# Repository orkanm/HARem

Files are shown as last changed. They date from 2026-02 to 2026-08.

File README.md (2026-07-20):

# HARem - Home Assistant Remote Controller



**HARem** is a high-performance, minimalist "Thin Client" remote controller designed for the modern smart home. Built on the **ESPHome** ecosystem and powered by the **ESP32-C3**, it provides a boutique-quality physical interface that prioritizes speed, aesthetics, and zero-maintenance operation.

<p align="center">
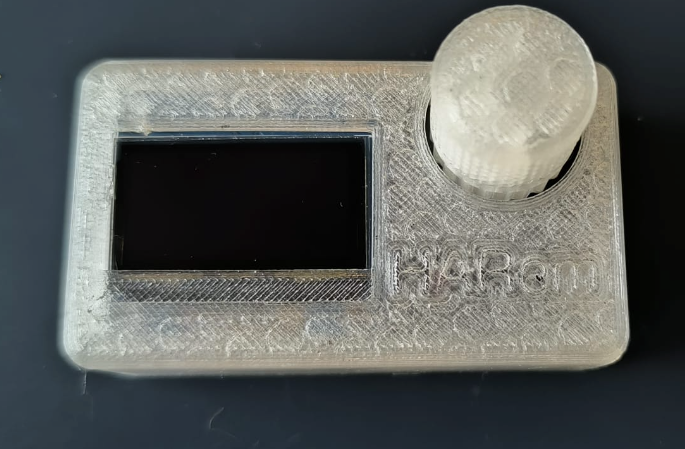
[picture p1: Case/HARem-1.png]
  
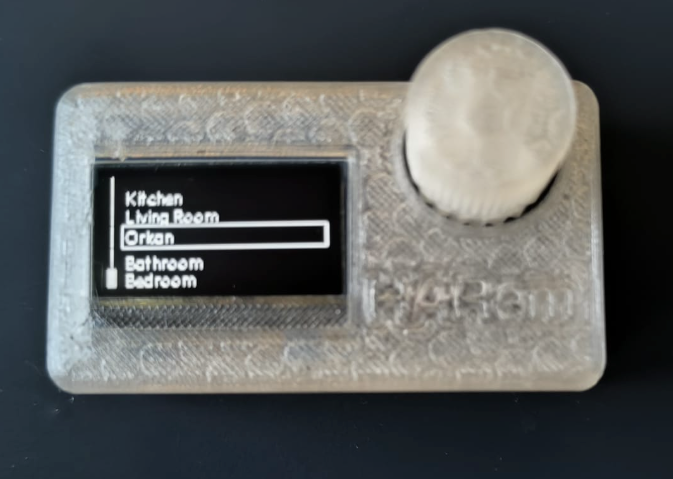
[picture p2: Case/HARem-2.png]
  
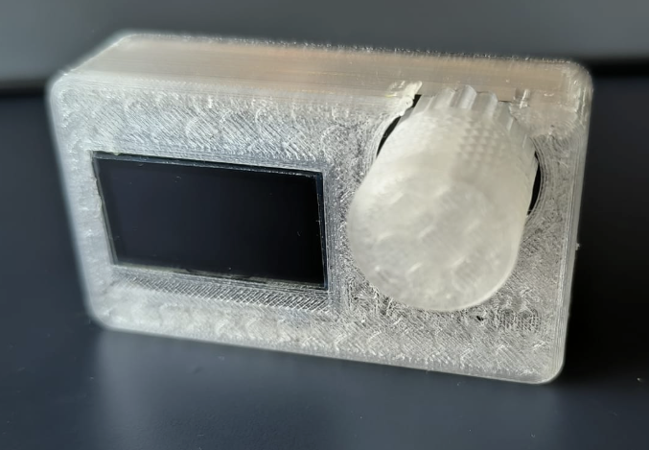
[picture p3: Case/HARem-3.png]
  
</p>

---

## ✨ Features & Architecture

Unlike traditional smart remotes that require manual configuration of every button, HARem operates as a **dynamic viewport** into your Home Assistant instance. Complex logic is handled by Home Assistant Blueprints and Automations, keeping the hardware lightweight and responsive.

- **Zero Maintenance**: Rooms, devices, and states are streamed in real-time. New devices added to a Home Assistant Area automatically appear on the remote.
- **Modern UI**: A 5-line **1.3" OLED** interface featuring Outfit and Montserrat typography, a vertical scrollbar, and hardware-accelerated dynamic marquee for long names.
- **Smart Power**: Deep sleep optimized for sub-1mA idle consumption, utilizing a high-impedance (1MΩ/1MΩ) battery divider and active OLED power management.
- **Guest Mode Protection**: Secure, PIN-protected "Guest Mode" to restrict access to specific areas or devices.
- **Visual Feedback & Control**: Interactive animations, sleep countdowns, and a local on-device menu for contrast and standby settings.

---

## 🚀 Quick Start

1. **Hardware**: ESP32-C3 SuperMini + 1.3" SH1106 OLED + EC11 Rotary Encoder.
2. **Firmware**: 
    * **Option A (Recommended)**: Download the latest **`.factory.bin`** from [Releases](https://github.com/orkanm/HARem/releases) and flash it to **offset 0x0**.
    * **Option B**: Compile locally using `esphome run remote_controller.yaml`.
3. **Home Assistant**: 
    * The device will appear as "HARem" in your dashboard.
    * **IMPORTANT**: If you used the GitHub Release binary, you will be asked for an **Encryption Key**:
        > `7knRB3/EL4Fq8Foul7Yhv+pcABzyLXHSQxa9bTzzQqg=`
    * > [!WARNING]
      > This key is **publicly known**. For security, you should change it in your own configuration and perform an [OTA update](https://esphome.io/components/ota.html) as soon as possible.
    * Follow the [Setup Guide](docs/generic_menu_setup.md) to create the required Helpers and import the logic Blueprint.

---

## 🛠️ Hardware & Assembly

Building your own HARem is straightforward. The project includes custom PCB files and 3D printable case models.

### Interactive Visualizers
Explore the design files directly in your browser:
* **[Interactive PCB 3D Viewer](https://3dviewer.net/index.html#model=https://raw.githubusercontent.com/orkanm/HARem/main/PCB/HARem/HArem.step)** (STEP format)
* **[Interactive Case 3D Viewer](https://3dviewer.net/index.html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,https://raw.githubusercontent.com/orkanm/HARem/main/Case/HARem_Case_2.0-Lid.stl,https://raw.githubusercontent.com/orkanm/HARem/main/Case/Encoder_Knob.stl)** (STL format)
* **[Interactive Schematic](https://kicanvas.org/?github=https://github.com/orkanm/HARem/blob/main/PCB/HARem/HArem.kicad_sch)**
* **[Interactive PCB Layout](https://kicanvas.org/?github=https://github.com/orkanm/HARem/blob/main/PCB/HARem/HArem.kicad_pcb)**

### Design Files
* **[KiCad Project](PCB/HARem/)**: Source files for schematic and board layout.
* **[PCB 3D Model](PCB/HARem/HArem.step)**: Industrial standard 3D file for enclosure design.
* **[3D Printed Case Files](Case/)**: Source FreeCAD project (`.FCStd`), print-ready `.stl` files for the case, lid, and knob, along with a high-resolution `.step` model.

<details>
<summary><b>View Wiring Diagram & Pin Mapping (Click to expand)</b></summary>

```text
       ESP32-C3 Super Mini                 Peripherals
    ┌───────────────────────┐            ┌───────────────┐
    │                       │   Q1(NPN)  │ 1.3" OLED     │
    │          5V / 3.3V ───┼────▶[C]    │               │
    │  GPIO1 (OLED PWR) ────┼────▶[B]    │               │
    │                       │     [E]────┼─▶ [VCC]       │
    │                GND ───┼────────────┼─▶ [GND]       │
    │         GPIO5 (SDA)───┼────────────┼─▶ [SDA]       │
    │         GPIO6 (SCL)───┼────────────┼─▶ [SCL]       │
    │                       │            └───────────────┘
    │                       │            
    │                       │            ┌───────────────┐
    │                       │            │ ROTARY (EC11) │
    │         GPIO8 (CLK) ◀─┼───[100Ω]───┼─ [CLK]        │
    │          GPIO9 (DT) ◀─┼───[100Ω]───┼─ [DT]         │
    │          GPIO4 (SW) ◀─┼───[100Ω]───┼─ [SW]         │
    │                GND  ◀─┼────────────┼─ [GND]        │
    │                       │            └───────────────┘
    │                       │            ┌───────────────┐
    │                       │            │ BAT MONITOR   │
    │                       │            │  [+] BATTERY  │
    │                       │            │   │           │
    │                       │            │  [1MΩ]        │
    │         GPIO0 (ADC) ◀─┼────────────┼───┤           │
    │                       │            │  [1MΩ] [0.1µF]│
    │                       │            │   │      │    │
    │                GND  ◀─┼────────────┼──GND────GND   │
    └───────────────────────┘            └───────────────┘
```

| Component | ESP32-C3 Pin | Type | Notes |
| :--- | :--- | :--- | :--- |
| **OLED VCC** | GPIO1 | Output | Active Power Management (via Q1 NPN) |
| **OLED SDA/SCL** | GPIO5 / GPIO6 | I2C | SSD1306/SH1106 |
| **Encoder CLK/DT** | GPIO8 / GPIO9 | Input | Navigation |
| **Encoder SW** | GPIO4 | Input | Wakeup Trigger |
| **Battery ADC** | GPIO0 | Analog | 1M/1M Divider + 0.1µF Cap |

</details>

---

## 📖 Documentation & Development

* **[Behavior & Interaction Map](docs/behavior_map.md)**: Visual state machines and logic flows for the device interaction.
* **[Project Walkthrough](docs/walkthrough.md)**: Architecture, features, and troubleshooting.
* **[Home Assistant Setup Guide](docs/generic_menu_setup.md)**: How to configure the Home Assistant side.
* **[Environment Installation & Setup Guide](docs/installation.md)**: Guide for setting up your local Python environment and secrets.
* **[Roadmap](TODO.md)**: Planned improvements and future features.

---

## 📛 Trivia: The Name HARem

The name **HARem** is a clever portmanteau of **H**ome **A**ssistant and **Rem**ote, but its inspiration runs deeper into Turkish history and culture. 

In Turkish and Ottoman history, the **Harem** represented the most private, sacred, and protected part of the household. By adopting this name, the project acknowledges the smart home as the modern individual's "inner sanctum." Just as the historical Harem was the heart of the home, this remote serves as the private, primary interface to control and protect the sanctity of your living space.

---

## ☕ Support the Project

If you find this project helpful and would like to support its development, you can buy me a coffee! Your support helps fund new prototypes and keeps the project open-source and free for everyone. 



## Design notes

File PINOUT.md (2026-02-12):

# HARem Hardware Pinout

This document outlines the hardware connections for the HARem Remote Controller (based on ESP32-C3 SuperMini).

## Pin Configuration

| GPIO Pin | Function | Mode | Notes |
| :--- | :--- | :--- | :--- |
| **GPIO 0** | Battery Voltage Monitor | ADC | Through voltage divider (Ultra Low Power: 2x 1MΩ + 0.1µF) |
| **GPIO 1** | OLED Power Supply | OUTPUT | Powers the display. Held LOW in deep sleep. |
| **GPIO 4** | Encoder Button | INPUT_PULLUP | Inverted, Used as Deep Sleep Wakeup Source |
| **GPIO 5** | I2C SDA | I2C Data | Connect to OLED SDA |
| **GPIO 6** | I2C SCL | I2C Clock | Connect to OLED SCL |
| **GPIO 7** | Free | - | - |
| **GPIO 8** | Encoder Pin B | INPUT_PULLUP | Rotary Encoder Clock/Data |
| **GPIO 9** | Encoder Pin A | INPUT_PULLUP | Rotary Encoder Clock/Data |

## Power Connections

- **3.3V**: Main power rail for Peripherals (Encoder, etc.)
- **GND**: Common Ground
- **5V / VBUS**: Charging Input (SuperMini handles charging)

## Power Consumption (Voltage Divider)
With the **Ultra Low Power** design (2x 1MΩ):
- **Resistance**: 2,000,000 Ω (2 MΩ)
- **Max Current (at 4.2V)**: `4.2V / 2MΩ = 2.1 µA`
- **Previous Design (2x 100k)**: `21 µA`
- **Savings**: ~90% reduction in divider leakage.

## Connection Diagram

```mermaid
graph LR
    subgraph ESP32_C3_SuperMini [ESP32-C3 SuperMini]
        GPIO0[GPIO 0<br>ADC0]
        GPIO4[GPIO 4<br>Wakeup]
        GPIO5[GPIO 5<br>SDA]
        GPIO6[GPIO 6<br>SCL]
        GPIO1[GPIO 1<br>Power]
        GPIO8[GPIO 8<br>Enc B]
        GPIO9[GPIO 9<br>Enc A]
        V33[3.3V]
        GND[GND]
    end

    subgraph Peripherals
        subgraph OLED [1.3" OLED Display]
            O_VCC[VCC]
            O_GND[GND]
            O_SDA[SDA]
            O_SCL[SCL]
        end

        subgraph Encoder [Rotary Encoder]
            E_SW[SW]
            E_DT[DT]
            E_CLK[CLK]
            E_COM[COM]
            R1[10k Pullup]
            R2[100 Ohm]
            R3[100 Ohm]
            R4[100 Ohm]
            C1[100nF]
        end

        subgraph Battery_Mon [Battery Monitor]
            BAT[+5VD / BAT]
            R5[1M]
            R6[1M]
            C2[0.1uF]
        end
    end

    %% Wiring
    GPIO1 -->|Power| O_VCC
    GPIO5 --- O_SDA
    GPIO6 --- O_SCL
    GND --- O_GND

    GPIO4 --- R2
    R2 --- E_SW
    E_SW --- R1
    R1 --- V33
    E_SW --- C1
    C1 --- GND

    GPIO8 --- R3
    R3 --- E_CLK
    GPIO9 --- R4
    R4 --- E_DT
    E_COM --- GND
    GND --- E_GND

    BAT --- R5
    R5 --- GPIO0
    GPIO0 --- R6
    R6 --- GND
    
    %% Capacitor for stability
    GPIO0 --- C2
    C2 --- GND
```

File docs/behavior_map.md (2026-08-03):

# HARem Extensive Behavior & Interaction Map

This document exhaustively details the state machines, interaction logic, system flows, and failure handling for the HARem controller, based directly on the ESPHome firmware configuration.

---

## 1. System States, Sleep & Power Flow

```mermaid
stateDiagram-v2
    direction TB
    [*] --> DeepSleep
    
    DeepSleep --> Boot : Button Press (GPIO4 Pulled LOW)
    
    state Boot {
        [*] --> WiFiConnect
        WiFiConnect --> APIConnect : Connects to Home Assistant
        APIConnect --> StaleStateClear : Send 'refresh' to HA (First wake only)
        StaleStateClear --> NormalOperation
    }
    
    Boot --> NormalOperation
    
    state NormalOperation {
        [*] --> IdleTimerRunning
        IdleTimerRunning --> SleepCountdown : Wait (Standby Duration)
        SleepCountdown --> DeepSleepPrep : Wait 5s
        SleepCountdown --> IdleTimerRunning : Any Input
    }
    
    DeepSleepPrep --> DeepSleep : Disconnect & Power Down OLED
```

### Deep Sleep & OLED Power Management
1. **Sleep Entry**: 
   - UI displays "SLEEPING" and a 5-second countdown timer.
   - Screen goes black in software.
   - `GPIO1` is pulled `LOW` and permanently locked using `gpio_hold_en()`. This guarantees the `Q1` NPN transistor cuts power to the OLED `VCC` rail entirely.
   - ESP32-C3 enters deep sleep for 1 day.
2. **Wake Up**:
   - Pushing the rotary encoder wakes the ESP32 via GPIO4.
   - Boot runs: `GPIO1` lock is released (`gpio_hold_dis()`), power is restored to the OLED, and a 100ms delay ensures OLED boot stability.
   - All internal UI states (`settings_mode`, `control_mode`, `guest_pin_mode`, etc.) are reset to `false` to prevent the UI from getting stuck if it went to sleep mid-interaction.

### The "Stale State Clear"
Because the remote connects to Home Assistant asynchronously after waking up, the controller checks `esp_sleep_get_wakeup_cause()`. If it woke from deep sleep, it sets `boot_clear_done = true` and sends a `refresh` event to Home Assistant to wipe out any leftover `line_5` or overlay dimming states from the previous session before rendering the UI.

---

## 2. Encoder Input & Normal Interaction Flow

```mermaid
flowchart TD
    Press[Button Pressed] --> HoldCheck{Hold Duration?}
    HoldCheck -->|"< 10ms"| Debounce(Ignore: Debounce)
    HoldCheck -->|"10ms - 800ms"| ShortClick(Short Click)
    HoldCheck -->|"800ms - 3.5s"| LongClick(Long Click)
    HoldCheck -->|"> 4s"| SettingsHold(Auto-Enter Settings)
    
    ShortClick --> ModeCheck{Current Mode?}
    ModeCheck -->|Control Mode| ExitControl[Exit Control Mode]
    ModeCheck -->|Settings Mode| SettingsAction[Execute Settings Action]
    ModeCheck -->|Normal Mode| ClickHA[Send 'click' to HA]
    
    LongClick --> LModeCheck{Current Mode?}
    LModeCheck -->|Settings Mode| CancelSettings[Exit Settings/Cancel PIN]
    LModeCheck -->|Normal Mode| BackHA[Send 'back' to HA]
```

### The "Sloppy Click" Filter
When pushing the encoder in **Control Mode**, it's common for a user's finger to accidentally rotate the knob a tiny bit during the press/release. 
- If `processed_rotate_hold` is flagged (meaning a rotation occurred while the button was down), the release event is consumed and *ignored* instead of triggering an exit click. This ensures smooth dimming without accidentally exiting.

### Normal Navigation
- **Rotate Clockwise (Free)**: Sends `esphome.remote_action` -> `next`
- **Rotate Counter-Clockwise (Free)**: Sends `esphome.remote_action` -> `prev`

---

## 3. Control Mode & Bulk Power Control Flow

Control Mode allows continuous parameter adjustment (like brightness or volume) or triggering Bulk Room Power Control without sending repetitive clicks.

```mermaid
stateDiagram-v2
    [*] --> Normal
    Normal --> PressAndTwist : Press + Rotate
    
    state PressAndTwist {
        direction LR
        [*] --> CheckLocation
        CheckLocation --> RoomList : ROOT Menu (Room List) ?
        RoomList --> SendBulkEvent : YES (Sends 'rotate_cw_hold' / 'rotate_ccw_hold')
        CheckLocation --> EntityList : In Room (Entity List) ?
        EntityList --> IsDimmable : Status has '*' ?
        IsDimmable --> SendDimEvent : YES (Control Mode & Dim Overlay)
        IsDimmable --> Reject : NO (Overlay 'Not Supported')
    }
    
    SendBulkEvent --> PromptActive : HA sets Overlay ('Turn ON Room?')
    PromptActive --> ExecuteBulk : Short Click on Prompt (Sends 'click' -> HA turns ON/OFF room)
    SendDimEvent --> SendDimEvent : Rotate (Adjusts Brightness/Vol)
    SendDimEvent --> Normal : Short Click (Exits Control Mode)
```

**Interaction Rules**:
1. **Bulk Room Power**: Executing Press & Twist on the `ROOT` menu sends `rotate_cw_hold` or `rotate_ccw_hold` to Home Assistant, prompting `Turn ON Room?` or `Turn OFF Room?`.
2. **Prompt Click Confirmation**: Short-clicking while a confirmation prompt (ending with `?`) is displayed fires `action: click`, triggering Home Assistant to execute the bulk power service across all included entities.
3. **Hotspot & OTA Guarding**: While the `WIFI FAILED!` hotspot overlay or `UPDATING...` OTA screen is active, all encoder rotations and button events are blocked locally to prevent background state drift.

---

## 4. Settings Menu State Machine

The settings menu is 100% locally rendered, decoupling critical device config from the Home Assistant server.

```mermaid
flowchart LR
    Enter[Hold >4s] --> Nav[Scroll Settings 0-10]
    Nav -->|Rotate| Nav
    Nav -->|Short Click| Eval[Evaluate Selection]
    
    Eval -->|Index < 4 or Index == 9| Edit[Toggle Edit Mode]
    Edit -->|Rotate| AdjustVar[Change Variable / Demo Mode]
    AdjustVar -->|Short Click| EditExit[Save & Exit Edit Mode]
    EditExit --> Nav
    
    Eval -->|Index 4, 5, 6, 7| Action[Toggle Guest / LeftHand / ChangePIN / WiFi Rescan]
    Eval -->|Index 10| Exit[Exit Settings]
```
    
    Eval -->|Index = 4 (Guest)| ToggleGuest[Toggle Guest]
    ToggleGuest -->|If ON| PINFlow
    ToggleGuest -->|If OFF| SendToggle[Send 'toggle_guest']
    
    Eval -->|Index = 6| PINFlow[Enter PIN Flow]
    Eval -->|Index = 7| Rescan[Rescan WiFi]
    Eval -->|Index = 9| Exit[Exit Settings]
```

### Editable Variables
1. **Brightness**: `10%` to `100%` (step 10) - Updates display contrast instantly.
2. **Standby Timer**: `10s` to `300s` (step 10) - `standby_duration_v2`
3. **Sleep Timer**: `10s` to `300s` (step 10) - `sleep_timeout_v2`
4. **Animations**: Toggle `enable_animations_v2` (1 or 0).
5. **Left Hand Mode**: Inverts display rendering 180° for left-handed use.

---

## 5. Security: PIN Validation & Change Flow

To prevent unauthorized users from leaving "Guest Mode", PIN validation is strictly enforced locally. 

```mermaid
flowchart TD
    Start[User selects Change PIN] --> Stage1[Verify Old PIN]
    
    Stage1 --> Input[Rotate 00-99, Click]
    Input --> Check1{Matches Old PIN?}
    
    Check1 -->|No| Error[Show 'WRONG!']
    Error --> Input
    
    Check1 -->|Yes| Stage2[Set New PIN]
    Stage2 --> Input2[Rotate 00-99, Click]
    Input2 --> Stage3[Confirm New PIN]
    
    Stage3 --> Input3[Rotate 00-99, Click]
    Input3 --> Check2{Matches Temp PIN?}
    
    Check2 -->|No| Error2[Show 'NO MATCH']
    Error2 --> Stage2
    
    Check2 -->|Yes| Success[Show 'PIN SAVED']
    Success --> SaveToMemory[Write Flash]
    SaveToMemory --> Exit[Exit PIN Flow]
```

---

## 6. Battery & OTA Behavior

### Battery Voltage Monitoring (ADC)
* Uses a high impedance `1MΩ / 1MΩ` voltage divider connected to `GPIO0`.
* The ADC reads raw voltage, multiplies by `2.0`, and converts to a strict `0-100%` scale assuming a LiPo range of `3.0V` to `4.1V`.
* **Low Battery UI Intercept**:
  * If `< 90%` upon boot, a 3-second warning is displayed.
  * If `< 20%` while awake, the screen flashes a high-priority, full-screen "LOW BATTERY!" warning immediately overlaying whatever was on screen.

### OTA Update Handling
* Over-The-Air updates trigger a high-priority override.
* `on_begin`: Idle timer is completely stopped, locking the screen `ON`.
* `on_progress`: Renders a custom full-screen progress bar (`ota_progress`).
* `on_end`: Shows "REBOOTING..." and reboots cleanly.

### Network Fallback
* If Wi-Fi drops, the ESP32 waits 3 minutes (`180s`). If connection isn't restored, it reboots.
* If it cannot connect to any configured Wi-Fi network, it falls back to AP (Captive Portal) Mode. The UI immediately detects this and draws a full-screen alert showing the Hotspot Name, Password, and IP for emergency provisioning.

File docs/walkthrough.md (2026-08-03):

# ESPHome Generic Remote Controller - Project Walkthrough

A universal, maintenance-free remote controller for Home Assistant, powered by ESPHome. It automatically discovers your Rooms and Devices, rendering them on a crisp OLED display.

## System Architecture

The remote operates as a "Thin Client". It handles physical I/O and displaying text, while Home Assistant handles all logic, state management, and menu rendering.

```mermaid
sequenceDiagram
    participant U as User
    participant R as ESPHome Remote
    participant HA as Home Assistant
    
    U->>R: Rotates Knob (Next)
    R->>HA: Fires event 'esphome.remote_action' (action: next)
    
    rect rgb(30, 30, 45)
        note right of HA: Automation Triggered
        HA->>HA: Calculate new Index
        HA->>HA: Fetch Areas/Devices List
        HA->>HA: Determine text for 5 Lines
    end
    
    HA-->>R: Updates 'input_text.harem_line_1'
    HA-->>R: Updates 'input_text.harem_line_2'
    HA-->>R: Updates 'input_text.harem_line_3' (Selected)
    HA-->>R: Updates 'input_text.harem_line_4'
    HA-->>R: Updates 'input_text.harem_line_5'
    
    R->>U: Display Refreshes
```

## Features

### 1. Zero-Maintenance Menu
*   **Dynamic**: No hardcoding device names on the chip.
*   **Auto-Sync**: Add a light to a room in HA -> It appears on the remote instantly.
*   **Hierarchical**: `Areas List` -> `Entities List` -> `Toggle Entity`.

### 2. High-Density Display
*   **5 Lines of Context**:
    *   **Lines 1, 2, 4, 5**: Contextual items (Small Font 10px).
    *   **Line 3**: Selected Item (Header Font 12px, highlighted with a **full-width outline box**).
*   **Vertical Scrollbar**: Positioned on the **left side** for better accessibility and aesthetics.
*   **Marquee Effect**: Long text on the selected line auto-scrolls with a hardware-accelerated UI mask to prevent spillover.

### 3. Navigation Controls
*   **Rotate**: Scroll Up/Down.
*   **Click**: Enter Room / Toggle Device. (Short Click: 10ms - 300ms)
*   **Long Press (301ms+)**: Back to previous menu. (No dead zone)

### 4. Smart Power Management
*   **Standby Mode**: Display turns off after 60s of inactivity to prevent burn-in.
*   **Wake-on-Click**: First click only wakes the device (no accidental actions).

### 5. Action Feedback
*   **Instant Feedback**: "Turning On..." / "Turning Off..." overlay appears immediately on click.
*   **Timeout Logic**: If device state doesn't change in 10s, displays "Failed!".
*   **Auto-Dismiss**: Overlay vanishes instantly when the new state is confirmed by Home Assistant.

### 6. Local Settings Menu
*   **Access**: Long press knob (>1.5s).
*   **Controls**: Rotate to Navigate, Click to Edit/Save.
*   **Features**:
    *   **Brightness**: Adjust OLED contrast (0-100%).
    *   **Standby**: Adjust timeout (10-300s).
    *   **Sleep**: Adjust sleep timeout (10-300s).
    *   **Animations**: Toggle smooth UI progress bar animations (ON/OFF).
    *   **Demo Mode**: Standalone offline demonstration mode (`Demo: [ON]` / `Demo: [OFF]`).
    *   **Network Info**: View SSID and IP Address.
*   **Storage**: Settings persist in flash memory (retained after reboot).

### 7. Emergency Hotspot (Changing WiFi)
If the remote cannot connect to any configured WiFi network (e.g., you changed your router password or moved to a new house):
1.  **Wait**: After powering on, wait 60 seconds.
2.  **Connect**: Look for WiFi named **"Harem Fallback Hotspot"** on your phone/laptop.
3.  **Password**: Enter `4jNJPSLAfajjdHh3`.
4.  **Configure**: A portal should pop up automatically (or go to `192.168.4.1`).
5.  **Select**: Click your new WiFi network and enter the password. The device will save it and reboot.

> [!NOTE]
> **Input Guarding**: While the "WIFI FAILED!" hotspot screen or OTA update screen is displayed, rotary encoder rotation and button press/release actions are completely suppressed to prevent background state modifications.

### 8. Final Verification (v0.7.0)
- **Startup**: Verified sequence (Splash -> Waiting -> v0.7.0).
- **Navigation**: "Back" button reliably returns to previous room.
- **Refresh Sync**: Explicit `refresh` event ensures the menu reappears instantly after exiting Dimming/Volume overlays.
- **Display**: Selection highlight moved to `x=8` to ensure pixel-perfect corners and zero interference with the scrollbar.
- **Versioning**: Centralized version management via `substitutions` block.

### 9. Final Verification (v0.7.1)
- **Linear Scrolling**: Verified that short menus correctly clamp at boundaries, avoiding duplicate wrapped items.
- **Dimming Status Evaluation**: Verified that dimming capabilities are correctly detected when the entity does not have a `friendly_name` attribute set.

### 10. Final Verification (v0.7.2)
- **Overlay Dismissal & Timeout**: Verified 5-second inactivity timeout and long-press BACK button overlay dismissal across bulk room power and individual device dimming modes.
- **Line 5 Sync**: Verified synchronized 5-line rendering upon returning from overlays.
- **Hotspot Overlay Input Protection (Issue #42)**: Verified that user inputs are ignored while hotspot or OTA overlays are active, and transient settings states reset cleanly upon entering hotspot mode.
- **Bulk Room Power Control**: Verified Press & Twist on room items on the ROOT menu forwards events to Home Assistant, and confirmed button clicks send `action: click` to execute bulk room turn on (`Turn ON Room?`) / turn off (`Turn OFF Room?`).

## 5. Next Steps
- [ ] Mount hardware in final enclosure.
- [ ] 3D Print case (files are available in the Case/ directory).
- [ ] Enjoy!

## Setup Guide

### 1. Home Assistant Helpers (Pick 1 of 2 Methods)

#### ✅ Option A: Drop-in Package (Professional)
The fastest method. Creates all 11 required helpers.
1. Copy [harem_package.yaml](../home_assistant/harem_package.yaml) to your Home Assistant `/config/packages/` folder.
2. In `configuration.yaml`, ensure you have: `homeassistant: { packages: !include_dir_named packages }`.
3. Restart Home Assistant. **Done.**

#### 🛠 Option B: Manual Configuration
Create these 11 Helpers manually in **Settings > Helpers**:

| Helper Entity ID | Type | Purpose |
| :--- | :--- | :--- |
| `input_text.harem_menu_path` | Text | Tracks current location (`ROOT` or Area Name). |
| `input_number.harem_menu_index` | Number | Tracks scroll position (0-1000). |
| `input_number.harem_menu_total` | Number | Tracks total number of items in the list. |
| `input_text.harem_line_1` | Text | Display Line 1 content. |
| `input_text.harem_line_2` | Text | Display Line 2 content. |
| `input_text.harem_line_3` | Text | Display Line 3 content (Selected). |
| `input_text.harem_line_3_status` | Text | Display Line 3 state (e.g. `(on) *`). |
| `input_text.harem_line_4` | Text | Display Line 4 content. |
| `input_text.harem_line_5` | Text | Display Line 5 content. |
| `input_text.harem_overlay` | Text | Feedback Screen Message (Pop-up). |
| `input_boolean.harem_guest_mode`| Toggle | Controls the security status. |

### 2. Home Assistant Automation (Blueprint)
All logic is handled securely via Blueprint.
1.  Copy the content of [harem_remote.yaml](../blueprints/harem_remote.yaml) into your Home Assistant `/config/blueprints/automation/` folder.
2.  Go to **Settings > Automations & Scenes > Blueprints**.
3.  Click **Create Automation** next to "HARem: Universal ESPHome Remote Controller".
4.  Select your helpers from the dropdowns and click **Save**.

**[View Setup Details](generic_menu_setup.md)**

### 3. ESPHome Firmware
The firmware handles hardware debouncing, display rendering, and event transmission.
**[View Firmware Config](../remote_controller.yaml)**

## Troubleshooting

### "Line 5 is missing"
*   **Cause**: You forgot to create `input_text.harem_line_5` in Home Assistant.
*   **Fix**: Create the text helper with that exact Entity ID.

### "Display is blank"
*   **Cause**: Automation hasn't run yet or inputs are empty.
*   **Fix**: Rotate the knob once to force an update.

### "Long press triggers click"
*   **Cause**: You released the button too fast (in the dead zone between 350ms-600ms).
*   **Fix**: Hold the button clearly for >0.6s until you see the action happen.

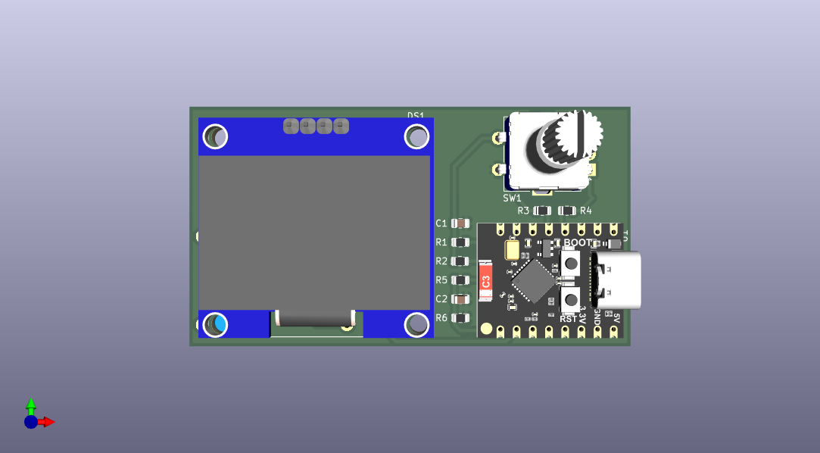
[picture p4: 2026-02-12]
PCB/HARem/HArem_PCB.png

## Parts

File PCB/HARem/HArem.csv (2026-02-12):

Id | Designator | Footprint | Quantity | Designation | Supplier and ref
1 | C2 | C_0805_2012Metric | 1 | 0.1uF
2 | R3,R4,R2 | R_0805_2012Metric | 3 | 100
3 | R6,R5 | R_0805_2012Metric | 2 | 1M
4 | C1 | C_0805_2012Metric | 1 | 100nF
5 | U1 | MODULE_ESP32-C3_SUPERMINI_TH | 1 | ESP32-C3_SUPERMINI_TH
6 | SW1 | RotaryEncoder_Alps_EC11E-Switch_Vertical_H20mm_MountingHoles | 1 | RotaryEncoder_Switch
7 | DS1 | LCD_OLED_128X64_1.3_I2C | 1 | OLED_128X64_1.3_I2C
8 | Q1 | SOT-23 | 1 | BC817
9 | R1 | R_0805_2012Metric | 1 | 10K
10 | U2 | TP4056-Module | 1 | ~
11 | J1 | JST_S2B-PH-K-S_LF__SN_ | 1 | S2B-PH-K-S_LF__SN_

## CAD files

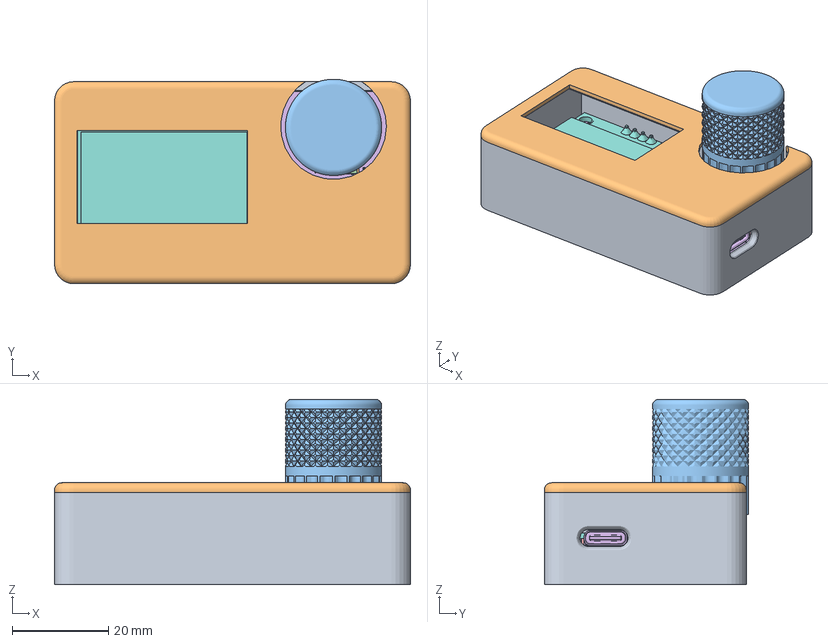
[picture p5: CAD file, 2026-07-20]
Case/HARem_Case_2.0.FCStd
74.0 x 42.5 x 38.5 mm
C_0805_2012Metric
R_0805_2012Metric
R_0805_2012Metric001
R_0805_2012Metric002
C_0805_2012Metric001
usb4215-03-a_1
RES0201 v1
C0201 v4
C0201 v001
C0402 v1
C0402 v001
C0201 v002
RES0201 v001
Cathode
Anode
Cathode Bar
QFN-32 V6 v2
C0201 v003
C0201 v004
C0201 v005
RES0201 v002
RES0201 v003
RES0201 v004
RES0201 v005
RES0201 v006
RES0201 v007
RES0201 v008
C0402 v002
switch 3x4x2mm - 2 Pad v2
switch 3x4x2mm - 2 Pad v001
C0201 v006
C0201 v007
C0201 v008
RES0201 v009
RES0201 v010
C0402 v003
C0201 v009
EC11 Rotary Encoder Dode Switch-15mm
R_0805_2012Metric003
Display 1.3 OLED (Mauro) v5
SOT-23
R_0805_2012Metric004
R_0805_2012Metric005
board
USB_Type_C_Connector
8205A_2045
DW01-P
small1005_smd_resistor
small1005_smd_resistor (1)
small1005_smd_capacitor
smd_capacitor
SOP-8_4056E
small1005_smd_resistor001
solder_dot_round
solder_dot_round (1)
solder_dot_round (2)
solder_dot_round (3)
small1005_smd_capacitor (1)
LED2
LED2 (1)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

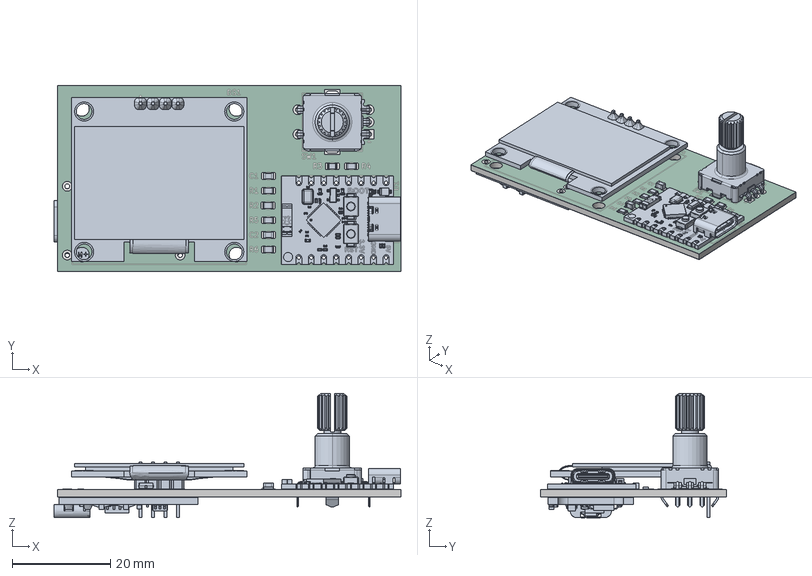
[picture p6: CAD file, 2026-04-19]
PCB/HARem/HArem.step
70.7 x 38.0 x 25.3 mm
C_0805_2012Metric x 2
R_0805_2012Metric x 6
usb4215-03-a_1
RES0201 v1 x 11
C0201 v4 x 10
C0402 v1 x 4
Cathode
Anode
Cathode Bar
QFN-32 V6 v2
switch 3x4x2mm - 2 Pad v2 x 2
EC11 Rotary Encoder Dode Switch-15mm
Display 1.3 OLED (Mauro) v5
SOT-23
board
USB_Type_C_Connector
8205A_2045
DW01-P
small1005_smd_resistor x 2
small1005_smd_resistor (1)
small1005_smd_capacitor
smd_capacitor
SOP-8_4056E
solder_dot_round
solder_dot_round (1)
solder_dot_round (2)
solder_dot_round (3)
small1005_smd_capacitor (1)
LED2
LED2 (1)
small1005_smd_resistor (2)
small1005_smd_resistor (4) x 2
soldering
HArem_copper
HArem_pad
HArem_via
HArem_silkscreen x 2
HArem_soldermask x 2
HArem_PCB

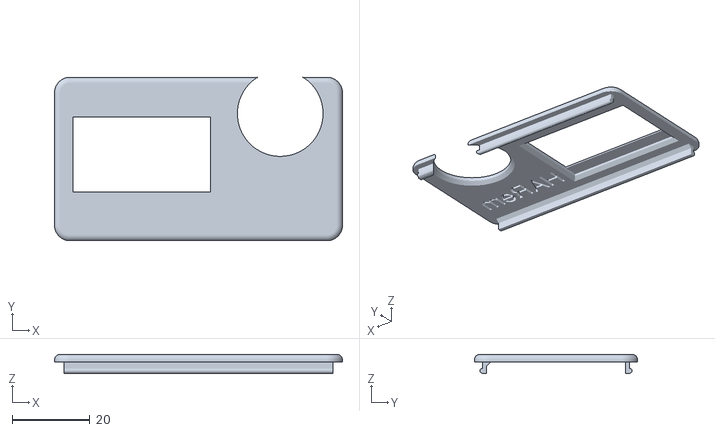
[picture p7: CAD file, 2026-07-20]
Case/HARem_Case_2.0-Lid.stl
74.0 x 42.0 x 5.00

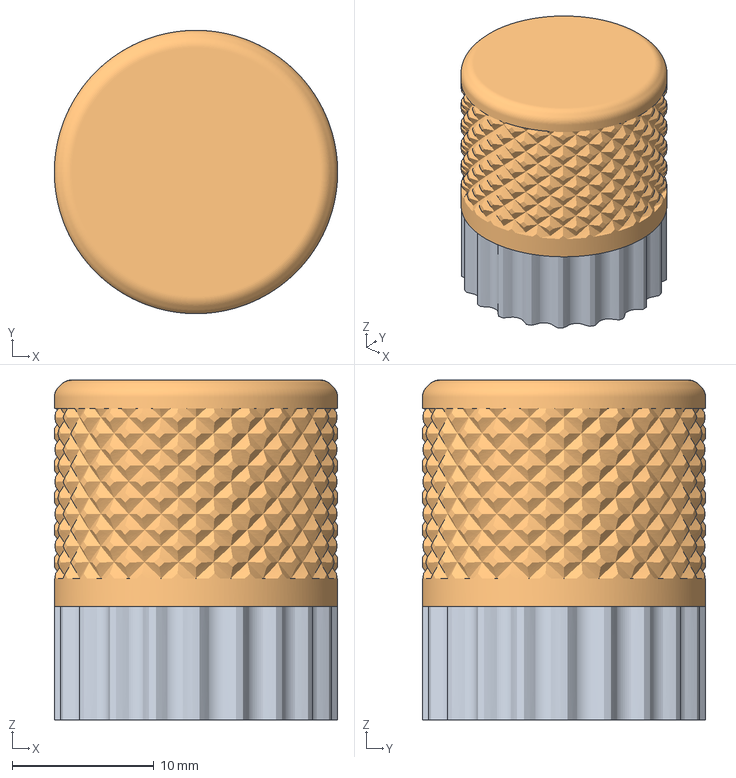
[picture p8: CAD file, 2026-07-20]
Case/Encoder_Knob.FCStd
20.0 x 20.0 x 24.0 mm
20mm

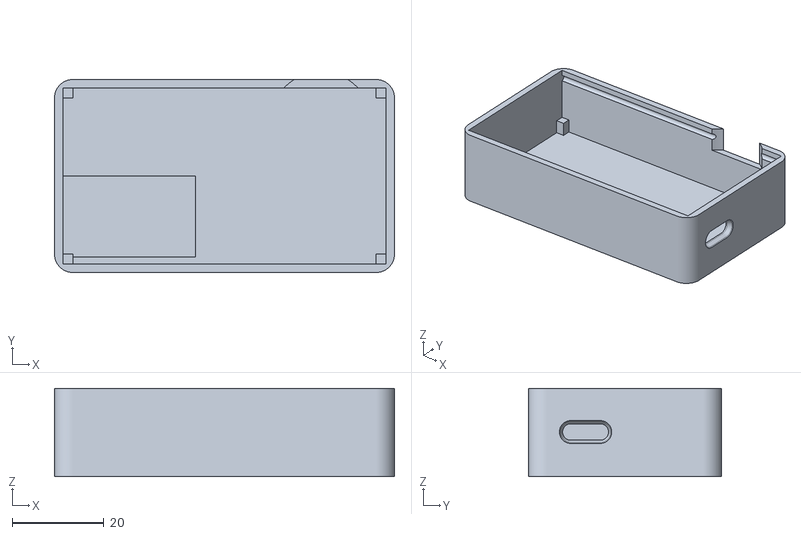
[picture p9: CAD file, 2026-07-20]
Case/HARem_Case_2.0-Case.stl
74.0 x 42.0 x 19.2

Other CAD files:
Case/Encoder_Knob.stl

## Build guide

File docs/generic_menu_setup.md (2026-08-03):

# Generic Menu Setup Guide

This guide turns your Remote into a universal browser for your Home Assistant "Areas".
It requires **no maintenance**—if you add a device to a Room in Home Assistant, it appears on the remote automatically.

> [!TIP]
> **New! One-Click Setup**
> * **[Download One-Click Package](../home_assistant/harem_package.yaml)** - Best for power users. Drop one file in, everything works.
> * **[Import Blueprint](../blueprints/harem_remote.yaml)** - Best for UI users. Pick your helpers from a dropdown.

---

## 1. Create Helpers (Choose Package or Manual)

### ✅ Option A: Drop-in Package (Recommended)
The fastest method. Creates all 11 required helpers instantly.
1. Download [harem_package.yaml](../home_assistant/harem_package.yaml) and place it in your Home Assistant `/config/packages/` folder.
2. In your `configuration.yaml`, ensure you have: `homeassistant: { packages: !include_dir_named packages }`.
3. Restart Home Assistant.

### 🛠 Option B: Manual Creation
If you don't use packages, manually create these in **Settings > Devices & Services > Helpers**:
1.  **Text Helper**: `input_text.harem_menu_path` (Name: "Remote: Menu Path")
2.  **Number Helper**: `input_number.harem_menu_index` (Name: "Remote: Menu Index", Min: 0, Max: 1000, Step: 1)
3.  **Number Helper**: `input_number.harem_menu_total` (Name: "Remote: Menu Total", Min: 0, Max: 1000, Step: 1)
4.  **Text Helper**: `input_text.harem_line_1` (Name: "Remote: Line 1")
5.  **Text Helper**: `input_text.harem_line_2` (Name: "Remote: Line 2")
6.  **Text Helper**: `input_text.harem_line_3` (Name: "Remote: Line 3")
7.  **Text Helper**: `input_text.harem_line_4` (Name: "Remote: Line 4")
8.  **Text Helper**: `input_text.harem_line_5` (Name: "Remote: Line 5")
9.  **Text Helper**: `input_text.harem_line_3_status` (Name: "Remote: Line 3 Status")
10. **Text Helper**: `input_text.harem_overlay` (Name: "Remote: Overlay")
11. **Toggle Helper**: `input_boolean.harem_guest_mode` (Name: "Remote: Guest Mode")

---

## 2. Apply the Blueprint Automation

All menu logic, dimming control, and screen updates are securely handled by the official Blueprint. Do not try to write this automation manually.

1. Copy the content of [harem_remote.yaml](../blueprints/harem_remote.yaml) into your Home Assistant `/config/blueprints/automation/` folder.
2. Go to **Settings > Automations & Scenes > Blueprints** and find "HARem: Universal ESPHome Remote Controller".
3. Click **Create Automation**.
4. Use the dropdowns to select the Helpers you created in Step 1.
5. Click **Save**.
```

## How to use
1.  **Start**: Ensure `input_text.harem_menu_path` is set to `ROOT`.
2.  **Navigate**: Rotate to scroll through Rooms.
3.  **Enter**: Click to enter a Room (lists devices in that Area).
4.  **Control**: Click to toggle a device.
5.  **Exit**: Long Press (>0.3s) the knob to go back to the Room list.

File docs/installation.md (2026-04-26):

# Environment Installation & Setup Guide

This guide will walk you through setting up your local development environment for the **HARem** project.

## Prerequisites

Before you begin, ensure you have the following installed on your system:

- **Python 3.11+**: The project is tested with recent Python versions.
- **python3-venv**: Required for creating isolated Python environments.
  - **On Ubuntu/Debian**:
    ```bash
    sudo apt update && sudo apt install -y python3-venv
    ```

## Step-by-Step Setup

### 1. Create a Virtual Environment

It is highly recommended to use a virtual environment to avoid dependency conflicts.

```bash
# Navigate to the project root
cd HARem

# Create the virtual environment
python3 -m venv esphome_venv
```

### 2. Activate and Install Requirements

Activate the environment and install the necessary Python packages (including ESPHome).

```bash
# Activate the environment
source esphome_venv/bin/activate

# Install requirements
pip install -r requirements.txt
```

### 3. Configure Secrets

The project uses a `secrets.yaml` file for sensitive information like Wi-Fi credentials and API keys. This file is excluded from Git.

1.  **Copy the template**:
    ```bash
    cp secrets_example.yaml secrets.yaml
    ```
2.  **Generate an API Key**:
    ESPHome requires a base64-encoded 32-byte key for API encryption. You can generate one using:
    ```bash
    openssl rand -base64 32
    ```
3.  **Edit `secrets.yaml`**:
    Open `secrets.yaml` in your editor and fill in the following:
    - `wifi_ssid`: Your Wi-Fi name.
    - `wifi_password`: Your Wi-Fi password.
    - `harem_api_key`: The base64 key generated in the previous step.
    - `harem_ota_password`: A password for Over-The-Air updates.

### 4. Validate Configuration

To ensure everything is set up correctly without needing hardware connected, run the validation command:

```bash
esphome config remote_controller.yaml
```

If you see `INFO Configuration is valid!`, you are ready to proceed.

## Building and Flashing

Once your hardware (ESP32-C3) is connected via USB:

```bash
# Compile and flash to the device
esphome run remote_controller.yaml
```

## Troubleshooting

- **Missing `python3-venv`**: If you get an error about `ensurepip`, run `sudo apt install python3-venv`.
- **Invalid API Key**: Ensure the `harem_api_key` in `secrets.yaml` is a valid base64 string.
- **Port Permission**: If you cannot flash, you may need to add your user to the `dialout` group:
  ```bash
  sudo usermod -a -G dialout $USER
  ```
  (Requires logout/login to take effect).

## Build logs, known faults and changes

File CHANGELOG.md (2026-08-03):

# Changelog

All notable changes to the HARem project will be documented in this file.

## [v0.7.2] - 2026-07-31

### Added
- **Demo Mode Settings Selection**: Refactored Demo Mode in the Settings menu to function consistently with other editable settings. Clicking selects the item (`Demo: [ON]` / `Demo: [OFF]`), dial rotation toggles the state, and clicking again confirms the selection.

### Fixed
- **Hotspot Overlay Input Protection (Issue #42)**: Added input guards for rotary rotation and encoder button presses when the Wi-Fi AP active (`wifi_component.is_ap_active()`) or OTA active (`ota_active`) overlay screen is displayed, preventing background settings or menu modifications. Active settings modes (`settings_mode`, `edit_mode`, `guest_pin_mode`, `control_mode`) are automatically reset to `false` upon entering hotspot mode.
- **Bulk Room Power Control & Click Confirmation**: Removed restrictive local dimmable `st.find("*")` check on ESP32 so Press & Twist events (`rotate_cw_hold` / `rotate_ccw_hold`) are forwarded to Home Assistant on both room items and dimmable items. Updated short-click handler in control mode to execute `send_click_event` when a confirmation prompt (`Turn ON Room?` / `Turn OFF Room?`) is active, enabling Home Assistant to execute the bulk room power command.
- **Linear Scrolling**: Fixed a bug where short menus (fewer than 5 items) padded the display with empty lines that wrapped improperly, causing blank gaps. Changed the logic to clamp list elements in short menus while retaining infinite circular scrolling for larger ones.
- **Dimming Status Evaluation**: Fixed an issue where the remote reported dimmable lights as "Not Supported !" because the entity was missing a `friendly_name` and the status template scoping prevented the dimming support asterisk (`*`) from rendering properly. Jinja loops scoping was simplified to directly fetch by modulus. Added a fallback to `object_id` when `friendly_name` is missing to prevent invisible elements.
- **Overlay Click Passthrough**: Fixed an issue where pressing the button while an active feedback overlay (e.g., "Living Room ON", "Living Room OFF", "Turning Off...") was displayed caused the remote to navigate into the room menu and toggle a device inside that room. Button presses while an active feedback overlay is showing now cleanly dismiss the overlay without triggering menu navigation or entity state changes.
- **Stale Status String Overwrite**: Fixed an issue where adjusting entity percentage (brightness/volume) caused the status string on the right of the entity to revert to an old value upon exiting control mode. The Blueprint now preserves the optimistic status string during `refresh` events and prevents active (`on`/`playing`) entities from falling back to `(off)` when Home Assistant attribute updates are delayed.
- **Line 5 Rendering Lag**: Fixed a visual delay where Line 5 appeared slightly after Lines 1–4 when returning from overlay screens in room menus. Removed premature `line_5` clearing service calls during overlay dismissal so that ESPHome renders all 5 menu lines simultaneously.
- **Bulk Room Power Timeout & Long Press Exit**: Extended bulk power confirmation prompt timeout to 5 seconds of inactivity and added support for long pressing the dial (`action: back`) on `ROOT` to immediately dismiss the prompt without executing the action.
- **Device Dimming & Volume Overlay Timeout**: Added a 5-second inactivity timeout for individual device brightness and volume adjustments. When dial rotation ceases for 5 seconds (or upon click/long-press), the overlay automatically clears and ESPHome exits control mode.
- **Long Press Overlay Dismissal in Rooms**: Fixed an issue where long pressing the dial (`action: back`) while an overlay was active inside a room menu incorrectly exited to `ROOT`. Long pressing while an overlay is active now only dismisses the overlay and keeps the user inside the current room menu.

## [v0.7.0] - 2026-05-02

### Added
- **UI Redesign**: Moved the vertical scrollbar to the left side and replaced the `>` bullet with a full-width outline selection box for a cleaner, modern look.
- **UI Masking**: Implemented a vertical hardware-accelerated mask at `x=0-5` to ensure marquee text doesn't spill over into the scrollbar area.
- **Synchronized Refresh**: Added a dedicated `refresh` event handler to the Blueprint and Remote to ensure the menu redraws instantly after adjustment overlays disappear.

### Fixed
- **Battery Logic**: Re-mapped battery percentage calculation to the correct voltage sensor and fixed the low-battery alert trigger threshold. Added hysteresis logic to prevent the percentage from incorrectly increasing during small voltage bounce-backs.
- **Battery Persistence**: Configured battery percentage and its baseline voltage to persist in RTC memory across deep sleep cycles.
- **Overlay Rendering**: Fixed an issue where the scrollbar and selection box were incorrectly drawn over local overlay warnings (like "Not Supported !").
- **UI Alignment**: Adjusted the top bar spacing to prevent the WiFi signal from being hidden behind the scrollbar mask and removed hyphens from the settings title to save space.
- **Scrollbar Stability**: Hardened the scrollbar logic with fallback values for `menu_total` to prevent the thumb from disappearing during transient network drops.
- **UI Artifacts**: Fixed "empty pixels" on the scrollbar corners by adjusting the selection box padding and drawing order.

---

## [v0.6.3] - 2026-04-12

### Fixed
- **Dimming Payload Rejections**: Bypassed a severe bug in the IKEA Home Smart integration where dimming commands caused fatal cache crashes by implicitly mapping `hs` capabilities against exclusively white-spectrum bulbs. Solved by dynamically injecting `color_temp` fallback variables explicitly into all `light.turn_on` action dictionaries natively within the Blueprint.
- **Pending Payload Interruptions ("Screen Stuck")**: Pressing the physical dial to confirm a dimming adjustment actively aborted any queued `250ms` payload payloads because the Home Assistant Blueprint ran in `mode: restart` during the event stream. The ESPHome firmware was refactored to bypass the Blueprint entirely and hit the underlying `input_text.set_value` HA Service natively. Additionally mitigated a C++ serialization fault in ESPHome by using invisible spaces (`" "`) instead of empty strings (`""`) to prevent board panic reboots.
- **Tracking Math Artifacts & Rubber-Banding**: Transitioned the visual dimming percentage tracker away from `Line 5` into the active parenthetical display string on `Line 3 Status` (e.g., `(30%) *`). Added rigorous 10% grid-snapping bounds, preventing confusing Zigbee physical approximations (like `29%`) from drifting into the UI during physical reads, and fixed an active-polling zero-bounds bug that stripped tracking strings aggressively when overshooting `(off)`.
- **Stale Room Name on Line 5**: Lines 4 and 5 were rendered whenever `.has_state()` returned true, which persists even after HA sends an empty string. Added `state != ""` guard matching the existing behaviour of line 3.
- **'Activating...' Stuck for 10 Seconds (Blueprint)**: The blueprint had its own separate 10s timeout. Reduced to **3 seconds**. Additionally, `scene`, `script`, and `button` entities never produce a detectable state change after activation, so the `wait_template` always timed out and wrongly showed **Failed!**. These instant-action entities now skip the wait and clear the overlay after 1 second instead.
- **Control Screen Persists After Deep Sleep Wake**: When the device entered deep sleep during a dimming (control mode) session, HA retained the stale `overlay` (e.g. `Bright 75%`, `MAX 100%`) and `line_5` brightness values. On wake-up, these were pushed back to the display. Fixed by (1) firing `clear_overlay` to HA on the first API reconnect after a deep sleep wake, and (2) extending the `is_stale_feedback` filter to also suppress `MAX`/`MIN` overlay texts, not just `Bright`/`Vol`.
- **False 'Failed!' Output on Slower Networks**: Increased the blueprint `wait_template` timeout safely up from 3 seconds to 5 seconds to completely eliminate frustrating "Failed!" overlay messages when interacting with gracefully fading Zigbee lights or Matter-over-Thread networks, which occasionally take ~3.5s to formally report a state change.
- **Outdated Device States on Wakeup**: Patched a UI desync vector where waking the screen (standby or deep sleep) would display stale cached information from hours prior if devices were modified elsewhere (like the HA App). Implemented an implicit `refresh` event boundary to force an unprompted state synchronization on wakeup.

---

## [v0.6.2] - 2026-02-12

### Added
- **Interactive Visualizers**: Integrated KiCanvas for interactive Schematics and PCB Layouts.
- **3D Design**: Added high-quality STEP model for industrial-grade enclosure design.
- **WiFi Provisioning**: Enabled **Improv Serial** and **Captive Portal** for easy setup on new networks.
- **Brand Identity**: Added ESPHome branding and corrected GitHub language detection.
- **Dashboard Integration**: Added `dashboard_import` for seamless ESPHome integration.

### Changed
- **Power Optimization**: Documented ultra-low-power design and standardized 1M/1M battery divider specs.
- **Repository Hygiene**: Optimized `.gitignore` and `.gitattributes` for a cleaner developer experience.
- **Hardware Accuracy**: Aligned all diagrams and specifications with the final PCB design.

---

## [v0.2] - 2026-01-03

### Added
- **One-Click Setup Package**: Added `home_assistant/harem_package.yaml` to automate helper and automation creation.
- **Home Assistant Blueprint**: Added `blueprints/harem_remote.yaml` for a UI-driven setup experience.
- **Emergency Hotspot Display**: The remote now displays WiFi failure alerts with the fallback hotspot name and password.
- **Security Hardening**: Rotated all API keys, OTA, and AP passwords.
- **Improved CI**: Optimized GitHub Actions to use `pip` for faster and more reliable firmware builds.

### Changed
- Refined rotary encoder timing and click sensitivity.
- Updated documentation with streamlined setup paths (Package vs Blueprint vs Manual).
- Synchronized local display passwords with secure secrets.

---

## [v0.1] - 2026-01-01

### Added
- Initial core firmware with 5-line menu system.
- Marquee scrolling for long device names.
- Standby mode and power management.
- Dynamic area and entity discovery via Home Assistant events.
- Initial GitHub Actions implementation for automated builds.

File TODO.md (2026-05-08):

# TODO - HARem Project Roadmap

This file tracks planned improvements and premium features for the HARem Remote Controller.

## 📋 System Enhancements
- [ ] **"About" Screen**: Add a settings item to display firmware version, system uptime, and WiFi signal strength.
- [ ] **Haptic Feedback**: Support for a mini vibration motor for tactile feedback during encoder rotation and button clicks.
- [x] **WiFi Provisioning**: Implement Improv WiFi and Captive Portal for easier setup (Added in v0.6.2).

## ✨ Visual & UX Refinements
- [ ] **UI Themes**: Support for switching between "Light" (Inverted) and "Dark" display modes.
- [ ] **Quick Favorites**: A dedicated top-level menu for the 3 most frequently used devices.
- [ ] **Icon Library Expansion**: Add specialized icons for common device types (HVAC, Curtains, Media Players).
- [ ] **Smooth Transition Effects**: Implement subtle slide or fade animations when navigating between menu levels.

## 🛠️ Hardware Integration (Future)
- [ ] **Auto-Brightness**: Support for external light sensors (e.g., BH1750) to dim the display in dark environments.
- [ ] **Advanced Power Metrics**: Track deeper battery health and discharge curves using on-device logging.

## 🔋 Power & Hardware Optimization (SuperMini)
- [x] **Battery Calibration**: Corrected `GPIO0` ADC mapping and low-battery thresholds (Fixed in v0.7.0).

---
*Maintained by Orkan Murat Celik*

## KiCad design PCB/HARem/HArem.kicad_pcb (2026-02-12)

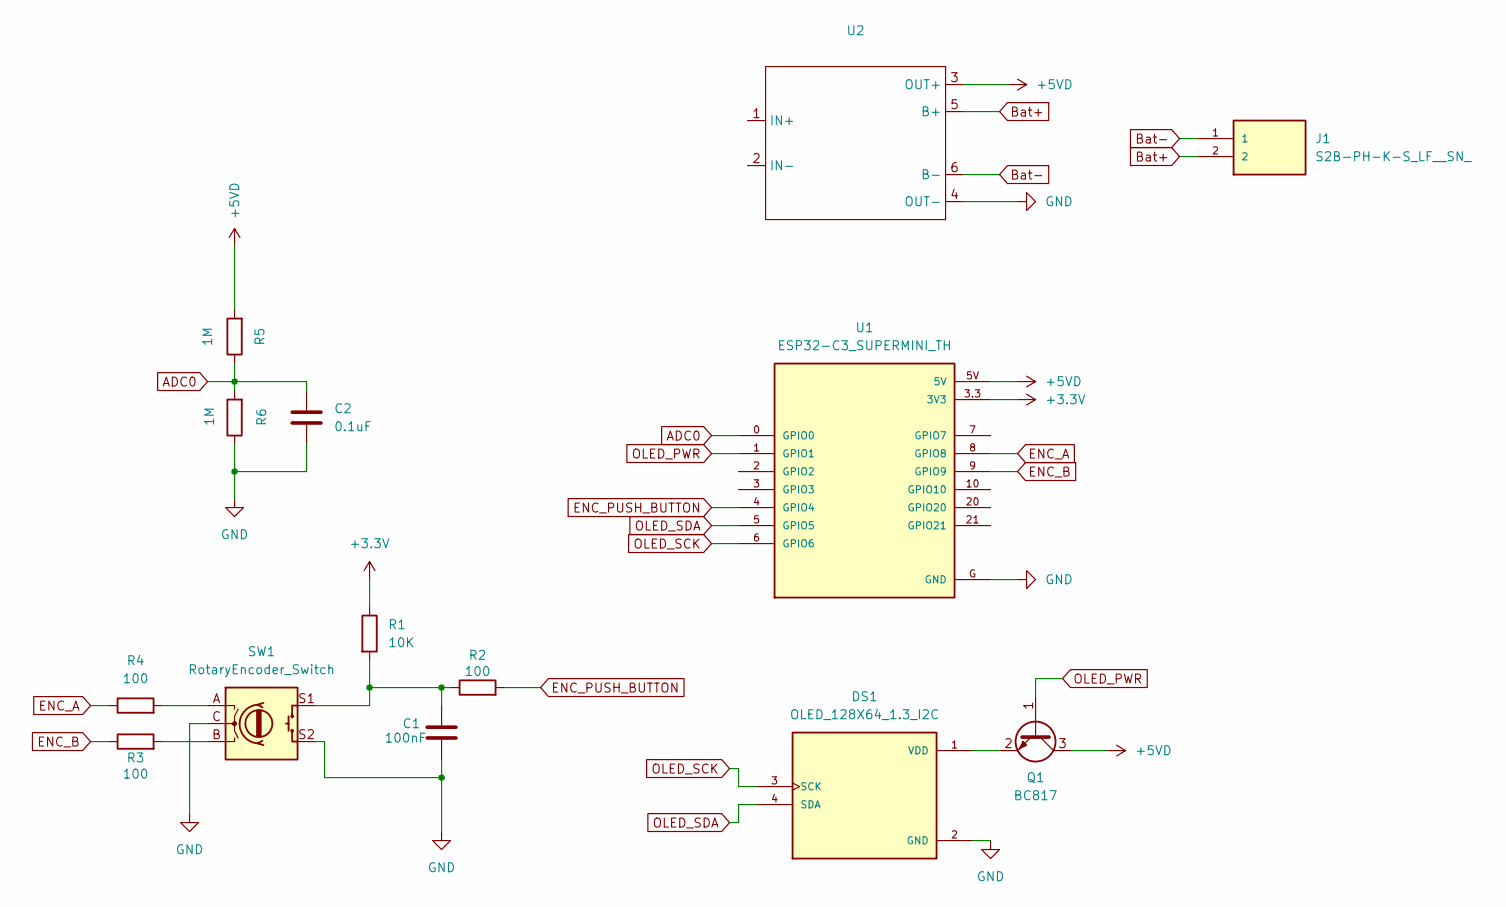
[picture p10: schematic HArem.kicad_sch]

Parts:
C1: 100nF; C_0805_2012Metric
C2: 0.1uF; C_0805_2012Metric
DS1: OLED_128X64_1.3_I2C; LCD_OLED_128X64_1.3_I2C; PARTREV NA
J1: S2B-PH-K-S_LF__SN_; JST_S2B-PH-K-S_LF__SN_
Q1: BC817; SOT-23
R1: 10K; R_0805_2012Metric
R2, R3, R4: 100; R_0805_2012Metric
R5, R6: 1M; R_0805_2012Metric
SW1: RotaryEncoder_Switch; RotaryEncoder_Alps_EC11E-Switch_Vertical_H20mm_MountingHoles
U1: ESP32-C3_SUPERMINI_TH; MODULE_ESP32-C3_SUPERMINI_TH
U2: TP4056-Module

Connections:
+3.3V: R1.1, U1.3.3 (3V3)
+5VD: Q1.3 (C), R5.2, U1.5V, U2.3 (OUT+)
ADC0: C2.1, R5.1, R6.2, U1.0 (GPIO0)
Bat+: J1.2, U2.5 (B+)
Bat-: J1.1, U2.6 (B-)
ENC_A: R4.1, U1.8 (GPIO8)
ENC_B: R3.1, U1.9 (GPIO9)
ENC_PUSH_BUTTON: R2.2, U1.4 (GPIO4)
GND: C1.2, C2.2, DS1.2 (GND), R6.1, SW1.C, SW1.S2, U1.G (GND), U2.4 (OUT-)
unnamed: C1.1, R1.2, R2.1, SW1.S1
unnamed: DS1.1 (VDD), Q1.2 (E)
unnamed: R3.2, SW1.B
unnamed: R4.2, SW1.A
OLED_PWR: Q1.1 (B), U1.1 (GPIO1)
OLED_SCK: DS1.3 (SCK), U1.6 (GPIO6)
OLED_SDA: DS1.4 (SDA), U1.5 (GPIO5)

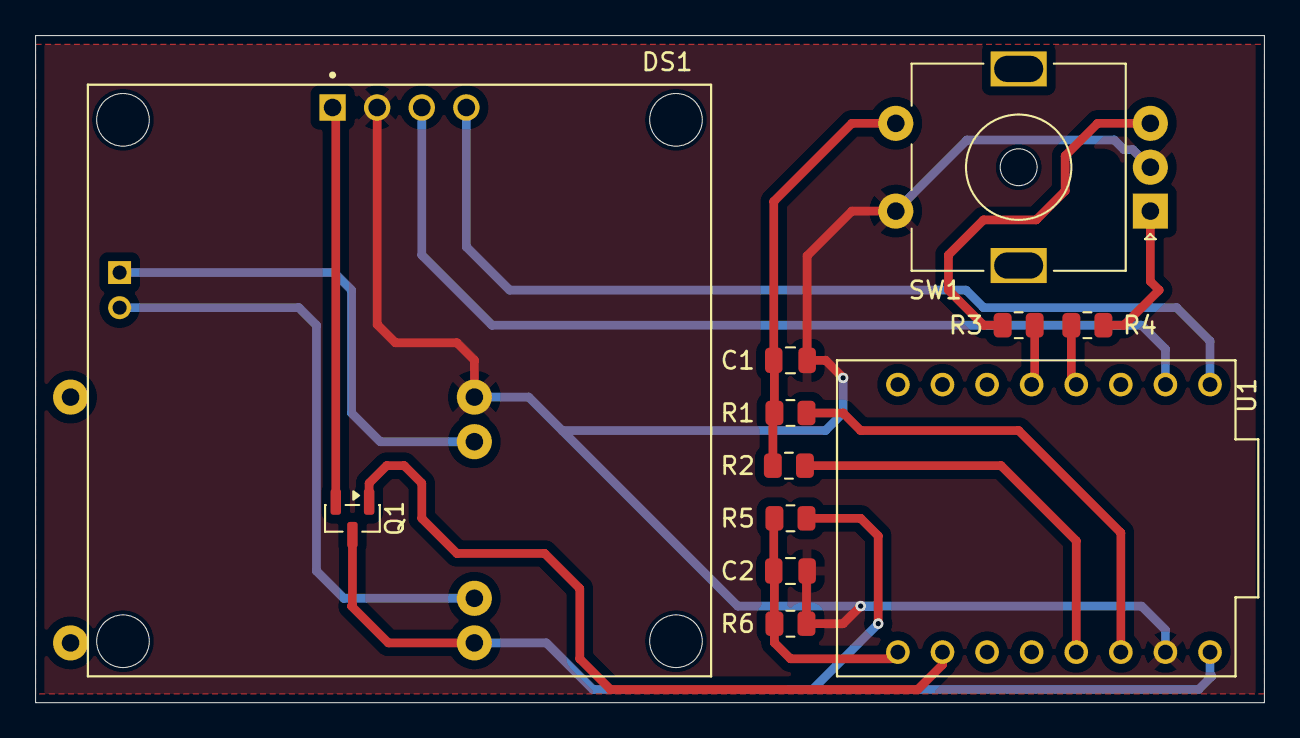
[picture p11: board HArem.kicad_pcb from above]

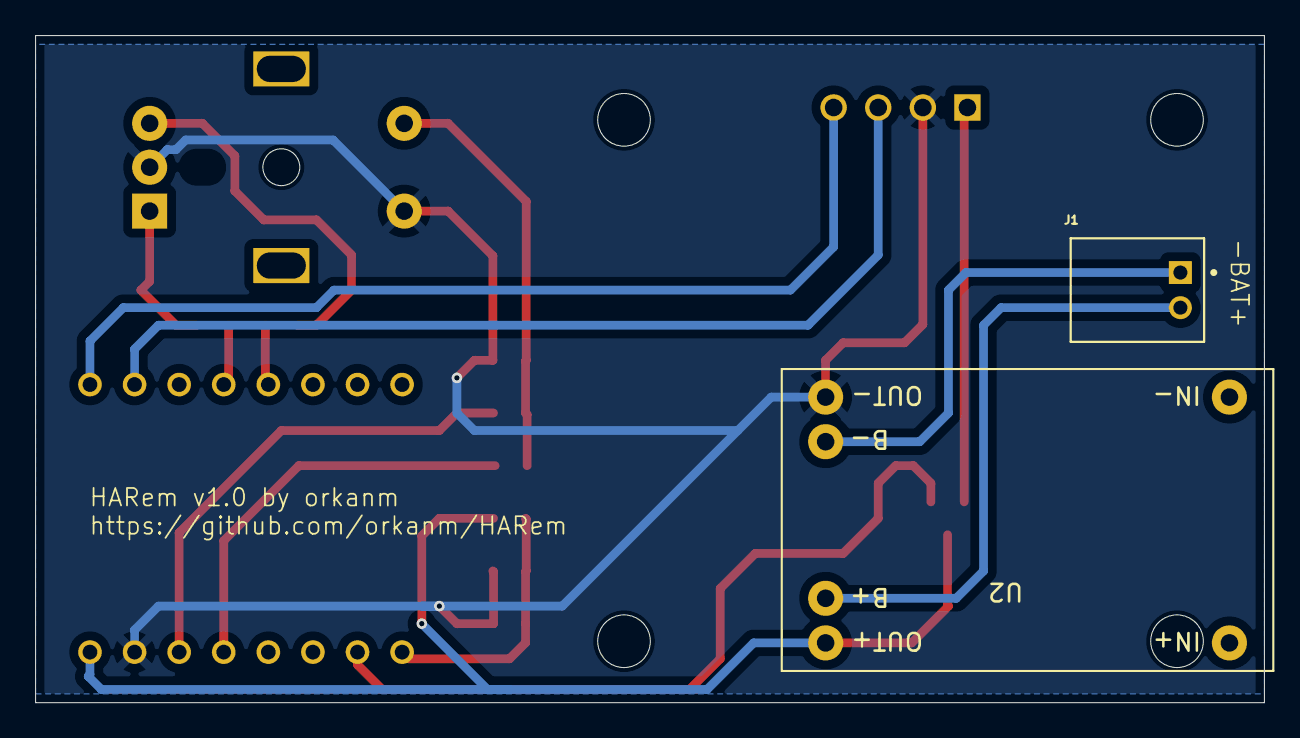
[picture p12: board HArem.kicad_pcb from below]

Board: 2 copper layers, 70.0 x 38.0 mm, 14 parts (2 on the bottom side), 16 nets.

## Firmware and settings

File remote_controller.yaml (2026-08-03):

# HARem - Home Assistant Remote Controller
# Maintained by Orkan Murat Celik

substitutions:
  name: "ha-remote"
  friendly_name: "HA Remote Controller"
  version_major: "0"
  version_minor: "7"
  version_patch: "2"
  version_prerelease: "-DEMO-MODE" # Set to "" for official releases, or "-rc.1", "-beta", etc.
  fw_version: "v${version_major}.${version_minor}.${version_patch}${version_prerelease}"

dashboard_import:
  package_import_url: github://orkanm/HARem/remote_controller.yaml

esphome:
  name: harem
  friendly_name: HARem
  project:
    name: "orkanm.harem"
    version: ${fw_version}
  on_boot:
    - priority: 800
      then:
        - lambda: |-
            esp_ota_mark_app_valid_cancel_rollback();
            gpio_hold_dis(GPIO_NUM_1); 
            id(oled_power).turn_on();
            // Force reset UI states on boot to prevent stuck screens
            id(settings_mode) = false;
            id(edit_mode) = false;
            id(control_mode) = false;
            id(guest_pin_mode) = false;
            id(pin_change_stage) = 0;
            id(input_pin) = 0;
        - delay: 100ms # Give OLED time to power up
    - priority: 500
      then:
        - script.execute: idle_timer
        - lambda: 'id(my_display).set_contrast(id(screen_brightness) / 100.0);'
    - priority: 400  # After idle_timer starts
      then:
        - lambda: |-
            if (id(battery_percent) < 90.0) {
              id(show_low_battery_warning) = true;
              id(my_display).update();
            }
        - delay: 3s  # Show warning for 3 seconds
        - lambda: |-
            id(show_low_battery_warning) = false;


esp32:
  board: esp32-c3-devkitm-1
  framework:
    type: esp-idf

# Enable Improv via Serial for easy provisioning
improv_serial:

# Enable logging
logger:
  level: DEBUG

preferences:
  flash_write_interval: 10s

# Enable Home Assistant API
api:
  encryption:
    key: !secret harem_api_key
  on_client_connected:
    then:
      - lambda: |-
          if (id(local_overlay_msg) == "Scanning WiFi...") {
            id(local_overlay_msg) = "";
            id(my_display).update();
          }
          // On first connect after deep sleep wake, clear any stale dimming
          // overlay/line_5 state left in HA from before sleep
          if (esp_sleep_get_wakeup_cause() != ESP_SLEEP_WAKEUP_UNDEFINED && !id(boot_clear_done)) {
            id(boot_clear_done) = true;
            id(send_refresh_event)->execute();
          }

ota:
  - platform: esphome
    on_begin:
      then:
        - script.stop: idle_timer
        - lambda: |-
            id(ota_active) = true;
            id(is_awake) = true;
            id(my_display).turn_on();
    on_progress:
      then:
        - lambda: |-
            id(ota_progress) = x;
            id(my_display).update();
    on_end:
      then:
        - lambda: |-
            id(ota_progress) = 100;
            id(my_display).update();
        - delay: 1s
    password: !secret harem_ota_password

wifi:
  id: wifi_component
  fast_connect: false
  networks:
    - ssid: !secret wifi_ssid
      password: !secret wifi_password

    - ssid: !secret 2_wifi_ssid
      password: !secret 2_wifi_password

    - ssid: !secret 3_wifi_ssid
      password: !secret 3_wifi_password
    # Set a low power save mode to speed up the connection when waking up
  power_save_mode: LIGHT
  
  # Callback when Wi-Fi disconnects
  on_disconnect:
    - logger.log: "Wi-Fi disconnected!"
    - delay: 180s   # wait 3 minutes
    - if:
        condition:
          wifi.connected:
        then:
          - logger.log: "Wi-Fi reconnected within 3 minutes."
        else:
          - logger.log: "Wi-Fi still down, rebooting..."

  # Enable fallback hotspot (captive portal) in case wifi connection fails
  ap:
    ssid: "Harem Fallback Hotspot"
    password: !secret harem_ap_password

captive_portal:

# Colors
color:
  - id: my_color_white
    red: 100%
    green: 100%
    blue: 100%
  - id: my_color_black
    red: 0%
    green: 0%
    blue: 0%

# I2C Configuration for OLED
i2c:
  sda: GPIO5
  scl: GPIO6
  frequency: 900kHz
  scan: true
  id: bus_a

# Font configuration
font:
  - file: "gfonts://Outfit"
    id: font_main
    size: 14
  - file: "gfonts://Material Icons"
    id: font_icon
    size: 24
    glyphs:
      - "\U0000E0F0" # lightbulb (was mdi-lightbulb-on)
      - "\U0000E8AC" # power_settings_new (was mdi-power-plug? using generic power for now)
      - "\U0000E335" # power_off (was mdi-lightbulb-off? using close/off)
      - "\U0000E02C" # movie
      - "\U0000E63C" # power (plug)
  - file: "gfonts://Montserrat"
    id: font_header
    size: 13
  - file: "gfonts://Outfit"
    id: font_small
    size: 10
  - file: "gfonts://Outfit"
    id: font_tiny
    size: 9
  - file: "gfonts://Bebas Neue"
    id: font_count
    size: 32
  - file: "gfonts://Outfit"
    id: font_medium
    size: 18
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

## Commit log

2025-12-31 Initial commit: ESPHome Remote Controller with 5-line generic menu
    [remote_controller.yaml]
2026-01-01 Fix: Rotary dir, entity filter, and toggle delay
    [remote_controller.yaml]
2026-01-01 Refactor: Display alignment and click sensitivity
    [remote_controller.yaml]
2026-01-01 Refactor: Enhanced startup sequence and documentation fixes
    [remote_controller.yaml]
2026-01-01 Fix: Update firmware version text to v0.1
    [remote_controller.yaml]
2026-01-01 Refactor: Move firmware version to substitutions block
    [remote_controller.yaml]
2026-01-01 Fix: Widen click timing to 850ms and update docs
    [remote_controller.yaml]
2026-01-01 Fix: Remove click dead zone (800ms split)
    [remote_controller.yaml]
2026-01-01 Fix: Set click timing to 300ms split per user request
    [remote_controller.yaml]
2026-01-02 Feat: Add Standby Mode and Action Feedback Screen
    [remote_controller.yaml]
2026-01-02 Finalize Settings Menu and Documentation
    [remote_controller.yaml]
2026-01-02 Switch CI to pip install to fix Docker error
2026-01-02 Move AP password to secrets.yaml
    [remote_controller.yaml]
2026-01-02 Add Hotspot Display Feature
    [remote_controller.yaml]
2026-01-02 Sync Hotspot Display password with rotated secrets
    [remote_controller.yaml]
2026-01-03 Bump version to v0.2 and add changelog
    [remote_controller.yaml]
2026-01-03 refactor: optimize button interaction using manual timing logic
    [remote_controller.yaml]
2026-01-03 feat: implement instant 5s settings trigger and two-way exit logic
    [remote_controller.yaml]
2026-01-03 feat: implement circular visual wrapping for settings menu
    [remote_controller.yaml]
2026-01-03 feat: refine button timings to 800ms (back) and 4s (settings)
    [remote_controller.yaml]
2026-01-03 feat: battery support, deep sleep, visual countdown, and optimized settings defaults
    [remote_controller.yaml]
2026-01-03 feat: add smooth sleep animations and UI polish
    [remote_controller.yaml]
2026-01-03 feat: add premium breathing animation to status overlay
    [remote_controller.yaml]
2026-01-03 feat: implement global animation toggle in settings
    [remote_controller.yaml]
2026-01-03 feat: complete animation toggle implementation
    [remote_controller.yaml]
2026-01-03 fix: resolve animation toggle persistence issue
    [remote_controller.yaml]
2026-01-03 docs: merge ABOUT.md into README for a unified landing page
2026-01-03 docs: consolidate hardware wiring into README and remove redundant schematic files
2026-01-14 feat(v0.6.0): Guest Mode PIN Security & Sleep Logic Fix
    [remote_controller.yaml]
2026-01-14 feat(ota): Add Visual OTA Feedback and fix sleep logic
    [remote_controller.yaml]
2026-01-14 feat(security): Implement On-Device PIN Change & Default to 00
    [remote_controller.yaml]
2026-01-14 chore: Bump version to v0.6.0-test
    [remote_controller.yaml]
2026-01-14 docs: Add PIN restriction constraint to roadmap
2026-01-14 Feature: Enhanced UI, Persistence Fixes & Multi-Device Guest Mode
    - Implemented absolute percentage feedback (0-100%) in overlay.
    - Removed progress bar for cleaner text-only interface.
    - Fixed menu persistence on fast 'Press & Twist' interactions.
    - Added support for multiple devices in Guest Mode selector.
    - Refactored blueprint state logic for stability.
    [remote_controller.yaml]
2026-01-20 optimize: Fix deep sleep drain (SuperMini 0.9mA), lock GPIO7, update TODOs
    [remote_controller.yaml]
2026-01-27 Add hardware pinout documentation with wiring diagram
2026-01-27 Update TODO with battery calibration details
2026-01-27 Update voltage divider design to Ultra Low Power (1MΩ + Cap)
    [remote_controller.yaml]
2026-02-11 Fix: Reverse encoder pins, fix stuck screen on boot, improve wake-up logic
    [remote_controller.yaml]
2026-02-12 Implement Left Hand Mode and Low Battery Warning with various UI fixes
    [remote_controller.yaml]
2026-02-12 Update documentation to match latest hardware (v1.0) and restore 1M battery divider
2026-02-12 docs: add PCB design and corrected hardware specifications
    [ESP32-C3_SUPERMINI_TH.step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]
2026-02-12 docs: add interactive 3D PCB viewer link
2026-02-12 docs: list Orkan Murat Celik as the maintainer
    [remote_controller.yaml]
2026-02-12 chore: bump version to v0.6.1-test
    [remote_controller.yaml]
2026-02-12 chore: update .gitignore to exclude KiCad local files
2026-02-12 chore: ignore ESP32-C3_SUPERMINI_TH folder
2026-02-12 chore: remove tracked library folder from git index
    [ESP32-C3_SUPERMINI_TH.step]
2026-02-12 docs: document low power consumption features
2026-02-12 feat: enable WiFi provisioning and cleanup repository
    [remote_controller.yaml]
2026-02-12 chore: consolidate WiFi configuration and remove duplicates
    [remote_controller.yaml]
2026-02-12 chore: fix dashboard_import and verify compilation
    [remote_controller.yaml]
2026-02-12 chore: release v0.6.2
    [remote_controller.yaml]
2026-02-24 Enforce 70s screen-on minimum uptime for OTA rollbacks
    [remote_controller.yaml]
2026-02-28 Update fw_version to v0.6.2-Fix
    [remote_controller.yaml]
2026-02-28 UI: Refactor OLED menus to left-aligned dynamic typography to fix tearing
    [remote_controller.yaml]
2026-03-07 Version number fix.
    [remote_controller.yaml]
2026-04-11 fix: stale line_5 display, instant-entity overlay, and 3s toggle timeout
    - remote_controller.yaml: guard line_4/line_5 rendering with empty-string
    check to prevent stale room names showing after navigation
    - harem_package.yaml: reduce toggle wait timeout from 10s to 3s
    - blueprints/harem_remote.yaml: same 3s timeout reduction; skip wait for
    instant-action entities (scene/script/button) which never produce a
    detectable state change, showing 'Activating...' for 1s instead of
    wrongly showing 'Failed!' after the full timeout
    [remote_controller.yaml]
2026-04-11 fix: clear stale dimming overlay after deep sleep wake
    Two fixes combined:
    1. On first HA connect after deep sleep wake, fire clear_overlay event
    to clean up any stale overlay/line_5 brightness state left in HA.
    Uses boot_clear_done flag to fire only once per boot.
    2. Extend is_stale_feedback check to also filter 'MAX' and 'MIN' overlay
    texts (hit when dimming reaches 0%/100%), which were previously shown
    on the full screen after wakeup despite control_mode being false.
    [remote_controller.yaml]
2026-04-12 Fix brightness adjustment latency and display lag in control mode
    * Changed blueprint automation mode to 'restart' to eliminate event queue backlog and latency during rapid encoder spins.
    * Changed send_rotate_cw/ccw_hold_event scripts to 'mode: single' to prevent redundant idle_timer restarts.
    * Reordered rotate_hold sequence so line_5 percentage and overlay update *before* the light/media service call, ensuring the screen stays perfectly responsive even if intermediate runs are restarted.
    * Changed relative brightness/volume steps to absolute values using the accumulated line_5 tracker, ensuring the final light state perfectly matches the screen display.
    * Wrapped the line_1-5 display upda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
    [remote_controller.yaml]
2026-04-12 fix(dimming): overhaul dirigera bypass, debouncing interrupts, and grid-snapping math
    [remote_controller.yaml]
2026-04-15 Fix UI state persistence and timeout for slower networks
    - Increased blueprint wait_template timeout from 3s to 5s to stop 'Failed!' overlays on slower Matter/Thread smart devices.
    - Added background refresh event to firmware to forcefully sync stale caching states when waking from screen standby or deep sleep.
    - Updated CHANGELOG to reflect fixes.
    [remote_controller.yaml]
2026-04-19 Fix PCB folder name capitalization and ignore cache/review file
    [HArem-B_Cu.gbr, HArem-B_Mask.gbr, HArem-B_Paste.gbr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]
2026-05-02 Final UI polish: unified display logic, hardened scrollbar, and synchronized menu refresh
    [remote_controller.yaml]
2026-05-02 Docs: Update README, CHANGELOG, and Walkthrough for v0.7.0 UI redesign
    [remote_controller.yaml]
2026-05-08 Fix battery percentage, deep sleep, and overlay errors
    [remote_controller.yaml]
2026-06-30 chore: bump firmware version to v0.7.1
    [remote_controller.yaml]
2026-07-20 feat(case): Add updated FreeCAD design (v2.0)
    [Encoder_Knob.FCStd, Encoder_Knob.stl, HARem_Case_2.0-Case.stl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]
2026-07-20 docs: Update documentation to include the new 3D printed case files
2026-07-20 docs: fix broken PCB directory links in README
2026-07-20 docs: Add case images and interactive 3D viewer link to README
2026-07-20 docs: Move Q1 transistor outside of the OLED box in the ASCII wiring diagram for clarity
2026-07-20 docs: Restore improved README structure and embed final corrected wiring diagram
2026-07-20 docs: Switch 3D Case viewer link to use STL files for faster loading
2026-07-25 feat: Add Press & Twist bulk room power control with confirmation prompt
    [remote_controller.yaml]
2026-07-31 Revert "feat: Add Press & Twist bulk room power control with confirmation prompt"
    [remote_controller.yaml]
2026-07-31 fix(remote): add 5s timeout, long-press exit, and overlay control_mode sync for bulk room power mode
    [remote_controller.yaml]
2026-07-31 feat(blueprint): add 5s inactivity timeout for device dimming/volume control overlays
2026-07-31 bump: bump version to v0.7.2
    [remote_controller.yaml]
2026-07-31 feat(remote): implement standalone Demo Mode for offline demonstration
    [remote_controller.yaml]
2026-07-31 fix(remote): add ON/OFF toggle support for dimmable light and speaker entities in Demo Mode
    [remote_controller.yaml]
2026-08-01 Semantic versioning is implemented.
    [remote_controller.yaml]
2026-08-03 fix(remote): prevent settings/menu changes behind wifi failed overlay (#42)
    [remote_controller.yaml]
2026-08-03 fix(remote): fix bulk room power control event sending and confirmation click (#42)
    [remote_controller.yaml]
